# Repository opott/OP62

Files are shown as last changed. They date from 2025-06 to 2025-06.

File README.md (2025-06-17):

# OP62
This is a 60% (62 key) mechanical keyboard designed for Hackpad V2.

## PCB
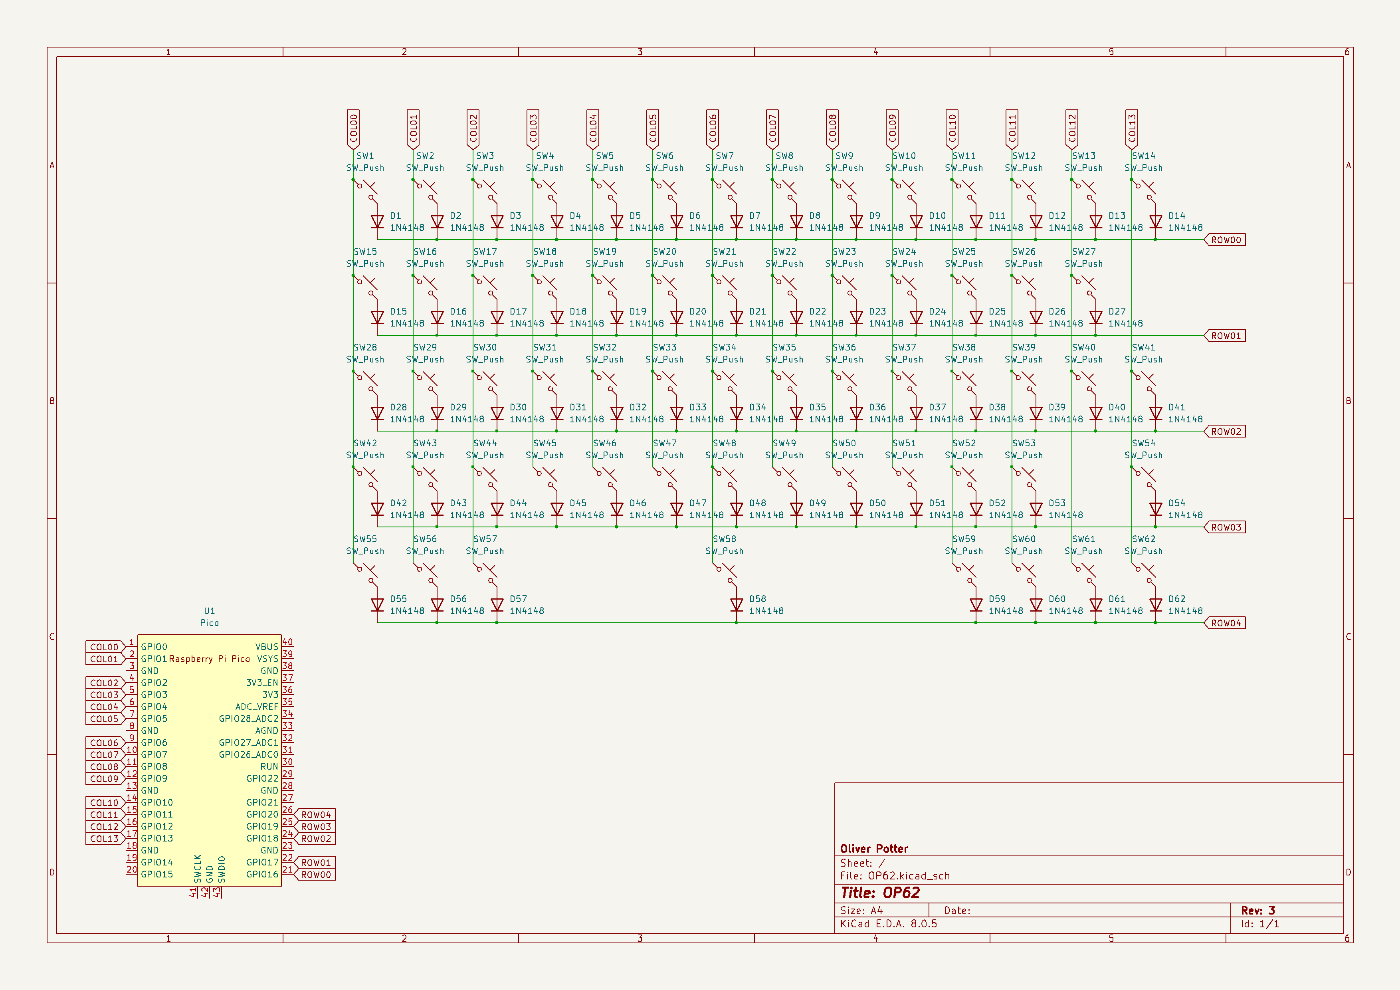
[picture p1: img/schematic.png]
schematic

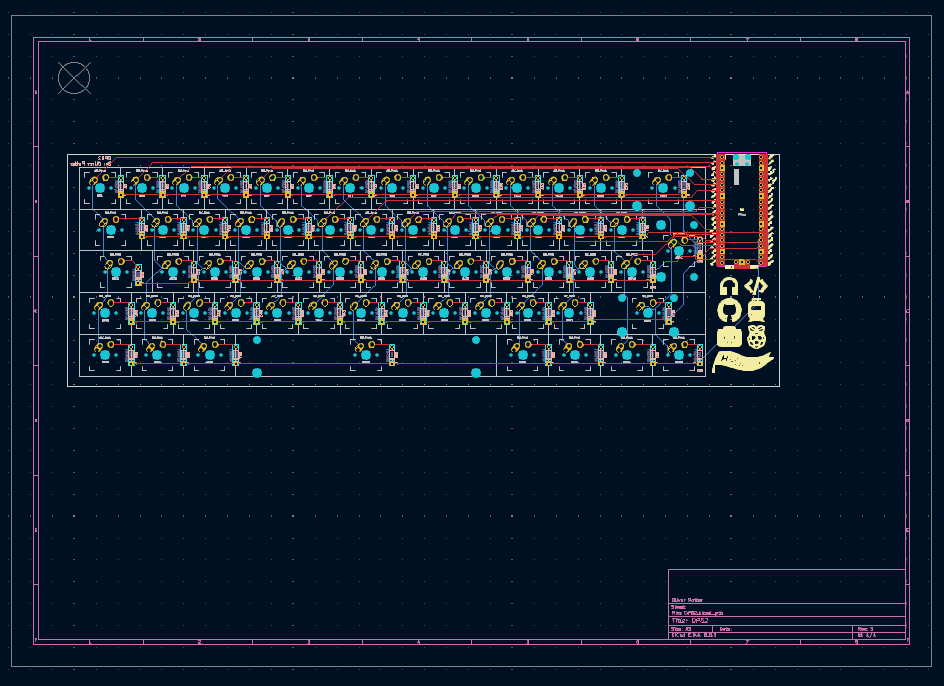
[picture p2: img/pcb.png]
pcb layout

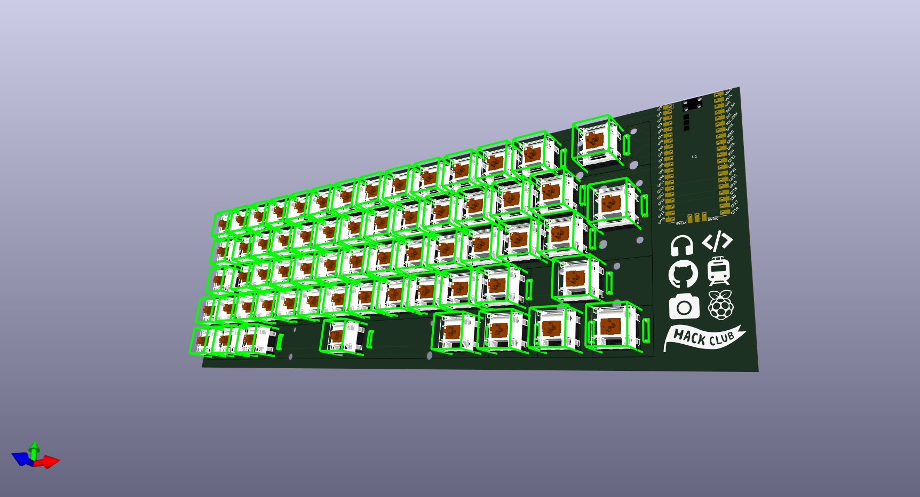
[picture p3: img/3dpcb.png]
3d view of pcb


## Case
The 3D printed case will consist of three parts:
- Top Assembly
- Plate
- Bottom Assembly

The top and bottom assembly will be attached with magnets. This is a screwless keyboard!
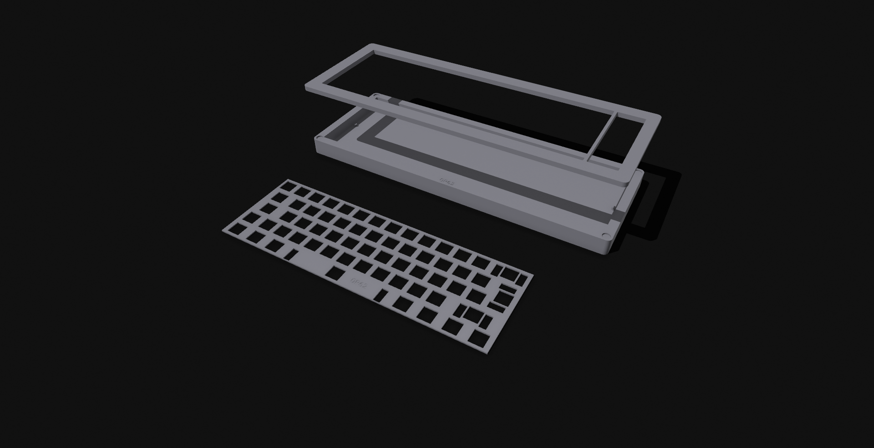
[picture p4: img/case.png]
case


## Firmware
The current firmware is a **VERY** basic prototype created with [Pog](https://pog.heaper.de/).

A final firmware version will be created upon recieving the hardware.

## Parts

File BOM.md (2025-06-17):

# OP62 - Bill of Materials
- PCB
    - **Vendor**: JLCPCB
    - **Price**: $28.77
        - **Merchandise Total:** $17.10
        - **Shipping Estimate:** $6.87
        - **Customs duties & taxes:** $4.80
- Orpheus Pico // Raspberry Pi Pico
    - With headers
    - To be supplied by HQ
- 3D Printed Case
    - To be printed by HQ
    - **Filament Colour:** White
- [Magnets](https://amzn.eu/d/0Vj31Tx)
    - **Purpose:** To hold the case together instead of screws.
    - **Vendor:** Amazon UK
    - **Price:** £5.99
- 62 [Prevail Epsilon Switches](https://www.mechmods.co.uk/products/prevail-epsilon-switches)
    - **Vendor:** MechMods UK
    - **Price:** 10 switches - £4.40 // Per switch ~£0.44 
- 62 1N4148 Diodes
- [White & Orange Double Shot PBT Keycaps](https://www.etsy.com/uk/listing/1345560507/isoansi-white-orange-double-shot-pbt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)
    - **Vendor:** KromeKeycaps // Etsy
    - **Price:** £24.99
- [TX AP Clip-in Stabilisers](https://www.mechmods.co.uk/products/tx-ap-clip-in-stabilisers?variant=44091474477279)
    - **Vendor:** MechMods UK
    - **Price:** £18.50

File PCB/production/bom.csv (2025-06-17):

Designator | Footprint | Quantity | Value | LCSC Part #
D1, D10, D11, D12, D13, D14, D15, D16, D17, D18, D19, D2, D20, D21, D22, D23, D24, D25, D26, D27, D28, D29, D3, D30, D31, D32, D33, D34, D35, D36, D37, D38, D39, D4, D40, D41, D42, D43, D44, D45, D46, D47, D48, D49, D5, D50, D51, D52, D53, D54, D55, D56, D57, D58, D59, D6, D60, D61, D62, D7, D8, D9 | D_DO-35_SOD27_P7.62mm_Horizontal | 62 | 1N4148
SW1, SW10, SW11, SW12, SW13, SW16, SW17, SW18, SW19, SW2, SW20, SW21, SW22, SW23, SW24, SW25, SW26, SW27, SW29, SW3, SW30, SW31, SW32, SW33, SW34, SW35, SW36, SW37, SW38, SW39, SW4, SW40, SW43, SW44, SW45, SW46, SW47, SW48, SW49, SW5, SW50, SW51, SW52, SW53, SW6, SW7, SW8, SW9 | MX-Alps-Hybrid-1U | 48 | SW_Push
SW14 | MX-Alps-Hybrid-2U | 1 | SW_Push
SW15 | MX-Alps-Hybrid-1.5U | 1 | SW_Push
SW28 | MX-Alps-Hybrid-1.75U | 1 | SW_Push
SW41 | MX-Alps-Hybrid-ISO | 1 | SW_Push
SW42, SW55, SW56, SW57, SW59, SW60, SW61, SW62 | MX-Alps-Hybrid-1.25U | 8 | SW_Push
SW54 | MX-Alps-Hybrid-2.75U | 1 | SW_Push
SW58 | MX-Alps-Hybrid-6.25U | 1 | SW_Push
U1 | RPi_Pico_SMD_TH | 1 | Pico

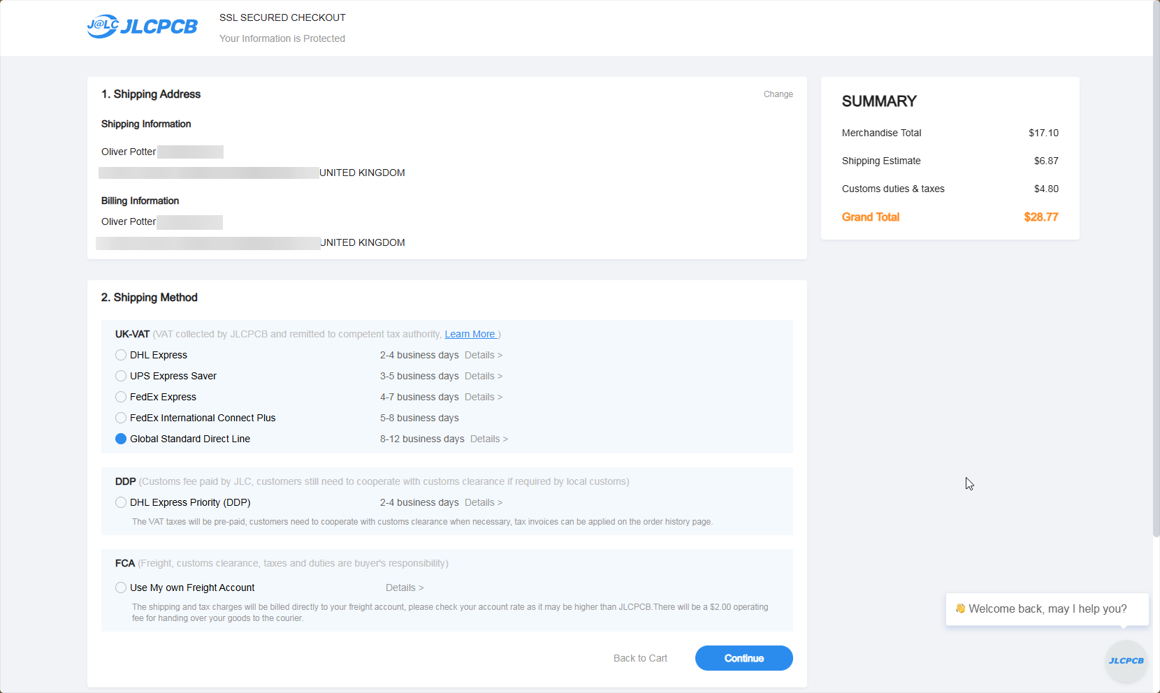
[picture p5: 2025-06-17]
img/bom/pcb.png

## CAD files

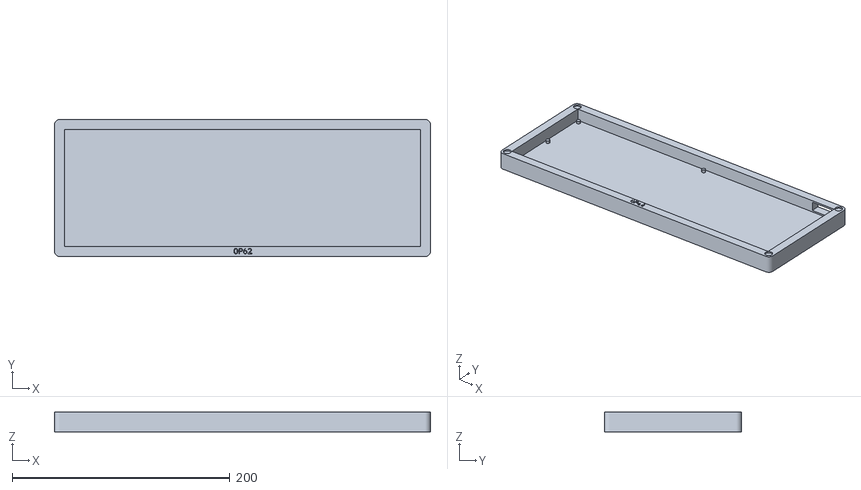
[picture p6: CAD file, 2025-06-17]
Production Files/Case/Bottom Assembly.stl
345.0 x 126.1 x 18.0

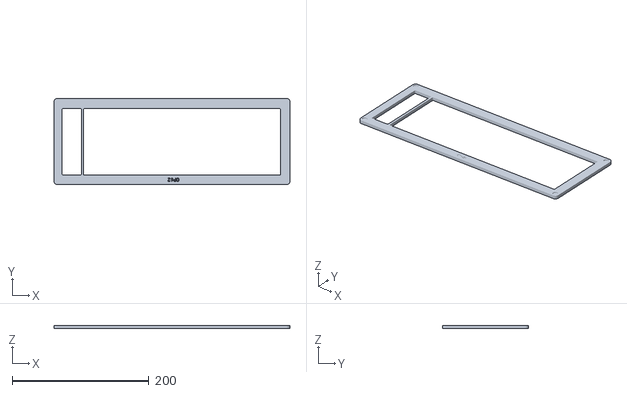
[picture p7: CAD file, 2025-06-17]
Production Files/Case/Top Assembly.stl
345.0 x 126.1 x 5.00

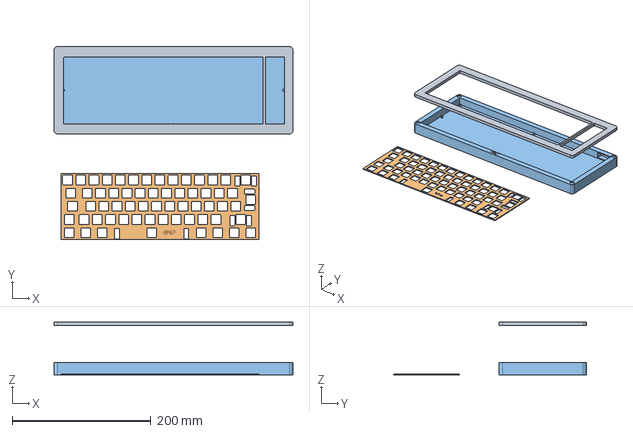
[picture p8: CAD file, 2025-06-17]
CAD/OP62.step
345.1 x 278.2 x 76.0 mm

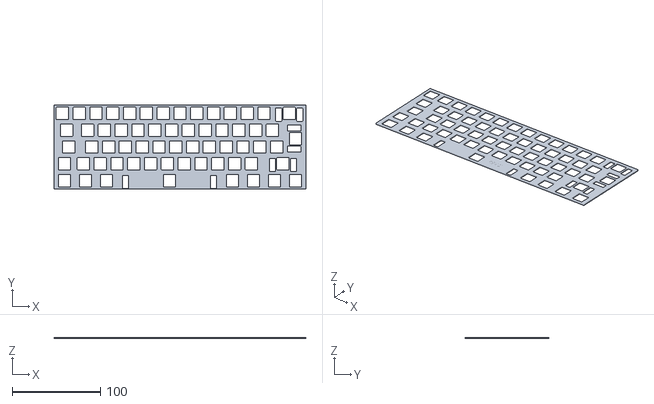
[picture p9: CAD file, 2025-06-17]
Production Files/Case/Plate.stl
285.8 x 95.2 x 1.50

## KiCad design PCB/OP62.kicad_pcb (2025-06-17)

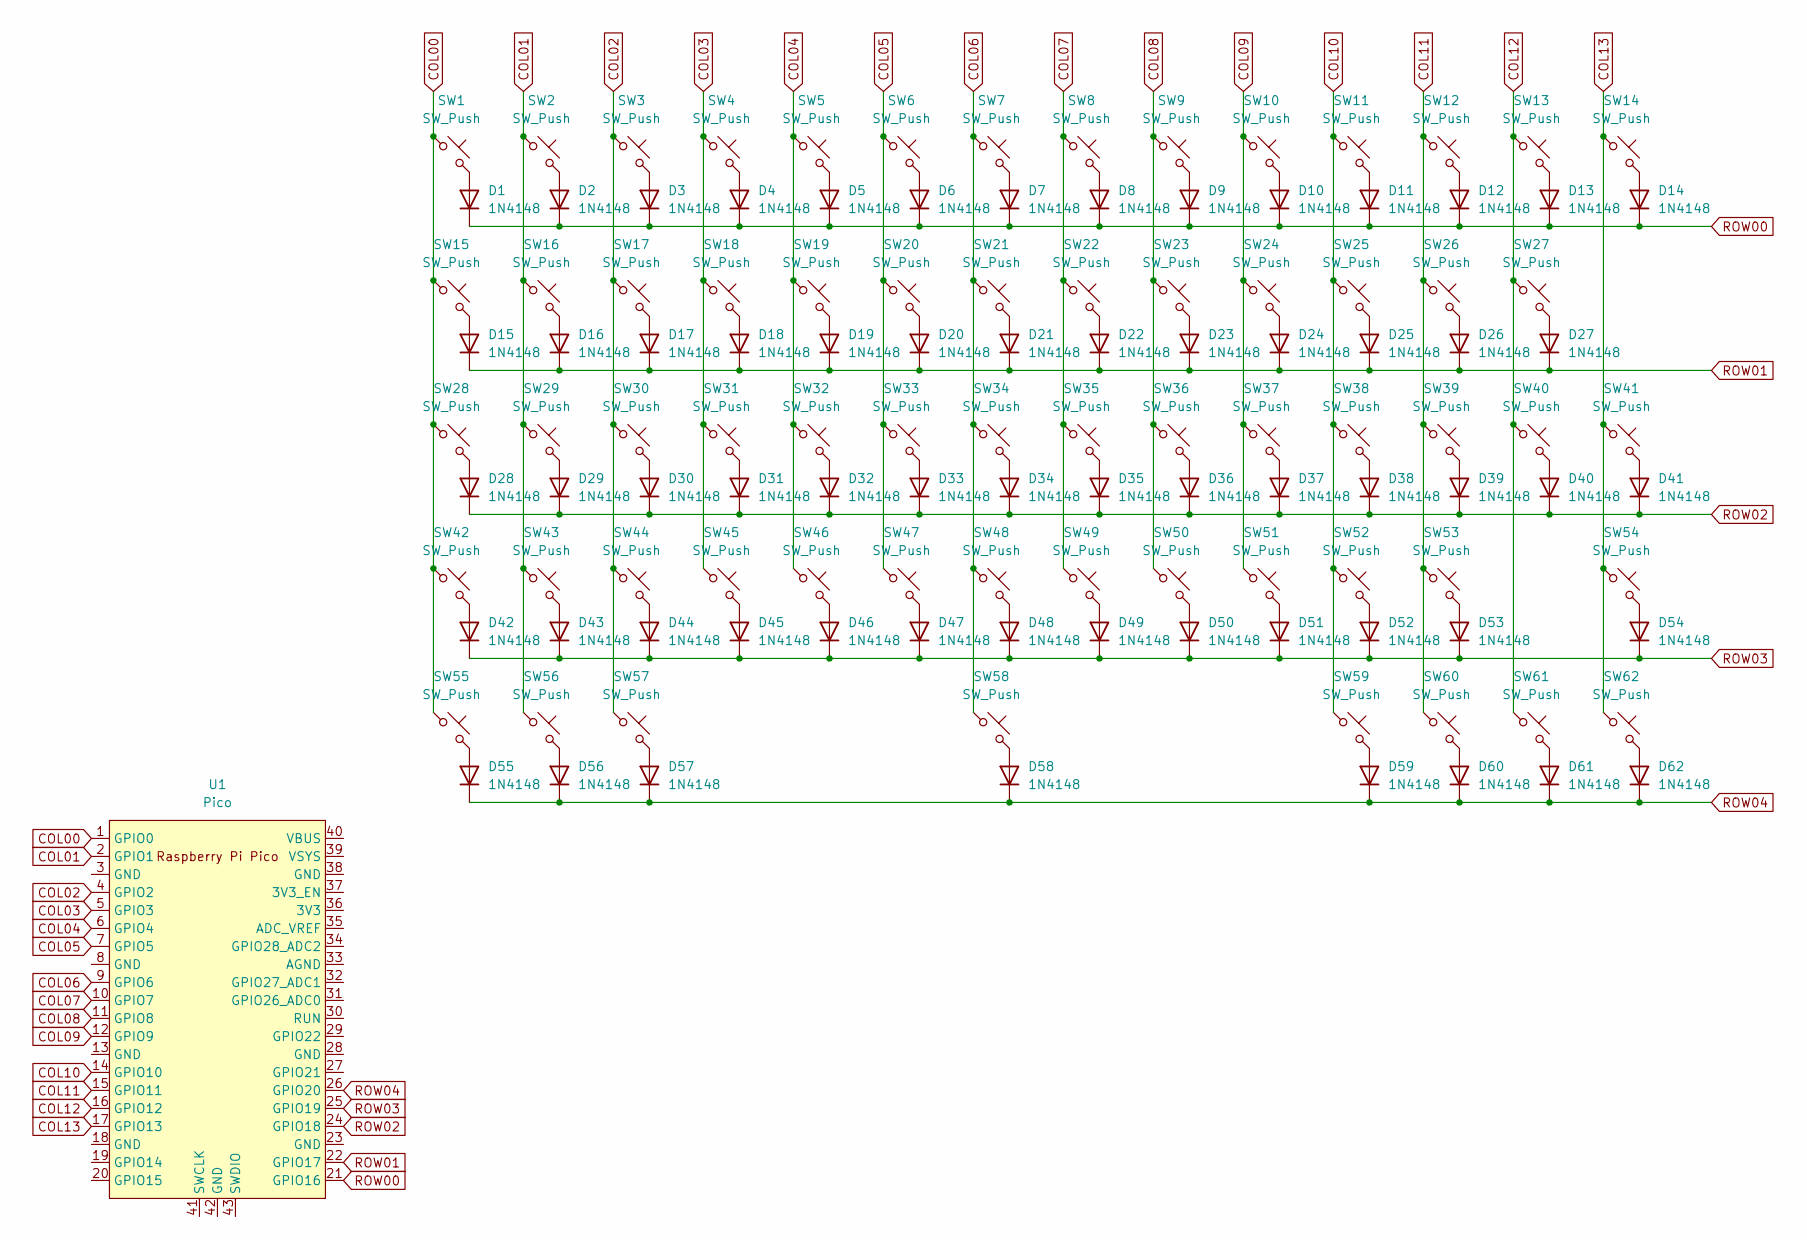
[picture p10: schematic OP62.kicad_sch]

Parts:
D1, D2, D3, D4, D5, D6, D7, D8, D9, D10, D11, D12, D13, D14, D15, D16, D17, D18, D19, D20, D21, D22, D23, D24, D25, D26, D27, D28, D29, D30, D31, D32, D33, D34, D35, D36, D37, D38, D39, D40, D41, D42, D43, D44, D45, D46, D47, D48, D49, D50, D51, D52, D53, D54, D55, D56, D57, D58, D59, D60, D61, D62: 1N4148; D_DO-35_SOD27_P7.62mm_Horizontal
SW1, SW2, SW3, SW4, SW5, SW6, SW7, SW8, SW9, SW10, SW11, SW12, SW13, SW16, SW17, SW18, SW19, SW20, SW21, SW22, SW23, SW24, SW25, SW26, SW27, SW29, SW30, SW31, SW32, SW33, SW34, SW35, SW36, SW37, SW38, SW39, SW40, SW43, SW44, SW45, SW46, SW47, SW48, SW49, SW50, SW51, SW52, SW53: SW_Push; MX-Alps-Hybrid-1U
SW14: SW_Push; MX-Alps-Hybrid-2U
SW15: SW_Push; MX-Alps-Hybrid-1.5U
SW28: SW_Push; MX-Alps-Hybrid-1.75U
SW41: SW_Push; MX-Alps-Hybrid-ISO
SW42, SW55, SW56, SW57, SW59, SW60, SW61, SW62: SW_Push; MX-Alps-Hybrid-1.25U
SW54: SW_Push; MX-Alps-Hybrid-2.75U
SW58: SW_Push; MX-Alps-Hybrid-6.25U
U1: Pico; RPi_Pico_SMD_TH

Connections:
COL00: SW1.1, SW15.1, SW28.1, SW42.1, SW55.1, U1.1 (GPIO0)
COL01: SW2.1, SW16.1, SW29.1, SW43.1, SW56.1, U1.2 (GPIO1)
COL02: SW3.1, SW17.1, SW30.1, SW44.1, SW57.1, U1.4 (GPIO2)
COL03: SW4.1, SW18.1, SW31.1, SW45.1, U1.5 (GPIO3)
COL04: SW5.1, SW19.1, SW32.1, SW46.1, U1.6 (GPIO4)
COL05: SW6.1, SW20.1, SW33.1, SW47.1, U1.7 (GPIO5)
COL06: SW7.1, SW21.1, SW34.1, SW48.1, SW58.1, U1.9 (GPIO6)
COL07: SW8.1, SW22.1, SW35.1, SW49.1, U1.10 (GPIO7)
COL08: SW9.1, SW23.1, SW36.1, SW50.1, U1.11 (GPIO8)
COL09: SW10.1, SW24.1, SW37.1, SW51.1, U1.12 (GPIO9)
COL10: SW11.1, SW25.1, SW38.1, SW52.1, SW59.1, U1.14 (GPIO10)
COL11: SW12.1, SW26.1, SW39.1, SW53.1, SW60.1, U1.15 (GPIO11)
COL12: SW13.1, SW27.1, SW40.1, SW61.1, U1.16 (GPIO12)
COL13: SW14.1, SW41.1, SW54.1, SW62.1, U1.17 (GPIO13)
unnamed: D1.2 (A), SW1.2
unnamed: D2.2 (A), SW2.2
unnamed: D3.2 (A), SW3.2
unnamed: D4.2 (A), SW4.2
unnamed: D5.2 (A), SW5.2
unnamed: D6.2 (A), SW6.2
unnamed: D7.2 (A), SW7.2
unnamed: D8.2 (A), SW8.2
unnamed: D9.2 (A), SW9.2
unnamed: D10.2 (A), SW10.2
unnamed: D11.2 (A), SW11.2
unnamed: D12.2 (A), SW12.2
unnamed: D13.2 (A), SW13.2
unnamed: D14.2 (A), SW14.2
unnamed: D15.2 (A), SW15.2
unnamed: D16.2 (A), SW16.2
unnamed: D17.2 (A), SW17.2
unnamed: D18.2 (A), SW18.2
unnamed: D19.2 (A), SW19.2
unnamed: D20.2 (A), SW20.2
unnamed: D21.2 (A), SW21.2
unnamed: D22.2 (A), SW22.2
unnamed: D23.2 (A), SW23.2
unnamed: D24.2 (A), SW24.2
unnamed: D25.2 (A), SW25.2
unnamed: D26.2 (A), SW26.2
unnamed: D27.2 (A), SW27.2
unnamed: D28.2 (A), SW28.2
unnamed: D29.2 (A), SW29.2
unnamed: D30.2 (A), SW30.2
unnamed: D31.2 (A), SW31.2
unnamed: D32.2 (A), SW32.2
unnamed: D33.2 (A), SW33.2
unnamed: D34.2 (A), SW34.2
unnamed: D35.2 (A), SW35.2
unnamed: D36.2 (A), SW36.2
unnamed: D37.2 (A), SW37.2
unnamed: D38.2 (A), SW38.2
unnamed: D39.2 (A), SW39.2
unnamed: D40.2 (A), SW40.2
unnamed: D41.2 (A), SW41.2
unnamed: D42.2 (A), SW42.2
unnamed: D43.2 (A), SW43.2
unnamed: D44.2 (A), SW44.2
unnamed: D45.2 (A), SW45.2
unnamed: D46.2 (A), SW46.2
unnamed: D47.2 (A), SW47.2
unnamed: D48.2 (A), SW48.2
unnamed: D49.2 (A), SW49.2
unnamed: D50.2 (A), SW50.2
unnamed: D51.2 (A), SW51.2
unnamed: D52.2 (A), SW52.2
unnamed: D53.2 (A), SW53.2
unnamed: D54.2 (A), SW54.2
unnamed: D55.2 (A), SW55.2
unnamed: D56.2 (A), SW56.2
unnamed: D57.2 (A), SW57.2
unnamed: D58.2 (A), SW58.2
unnamed: D59.2 (A), SW59.2
unnamed: D60.2 (A), SW60.2
unnamed: D61.2 (A), SW61.2
unnamed: D62.2 (A), SW62.2
ROW00: D1.1 (K), D2.1 (K), D3.1 (K), D4.1 (K), D5.1 (K), D6.1 (K), D7.1 (K), D8.1 (K), D9.1 (K), D10.1 (K), D11.1 (K), D12.1 (K), D13.1 (K), D14.1 (K), U1.21 (GPIO16)
ROW01: D15.1 (K), D16.1 (K), D17.1 (K), D18.1 (K), D19.1 (K), D20.1 (K), D21.1 (K), D22.1 (K), D23.1 (K), D24.1 (K), D25.1 (K), D26.1 (K), D27.1 (K), U1.22 (GPIO17)
ROW02: D28.1 (K), D29.1 (K), D30.1 (K), D31.1 (K), D32.1 (K), D33.1 (K), D34.1 (K), D35.1 (K), D36.1 (K), D37.1 (K), D38.1 (K), D39.1 (K), D40.1 (K), D41.1 (K), U1.24 (GPIO18)
ROW03: D42.1 (K), D43.1 (K), D44.1 (K), D45.1 (K), D46.1 (K), D47.1 (K), D48.1 (K), D49.1 (K), D50.1 (K), D51.1 (K), D52.1 (K), D53.1 (K), D54.1 (K), U1.25 (GPIO19)
ROW04: D55.1 (K), D56.1 (K), D57.1 (K), D58.1 (K), D59.1 (K), D60.1 (K), D61.1 (K), D62.1 (K), U1.26 (GPIO20)

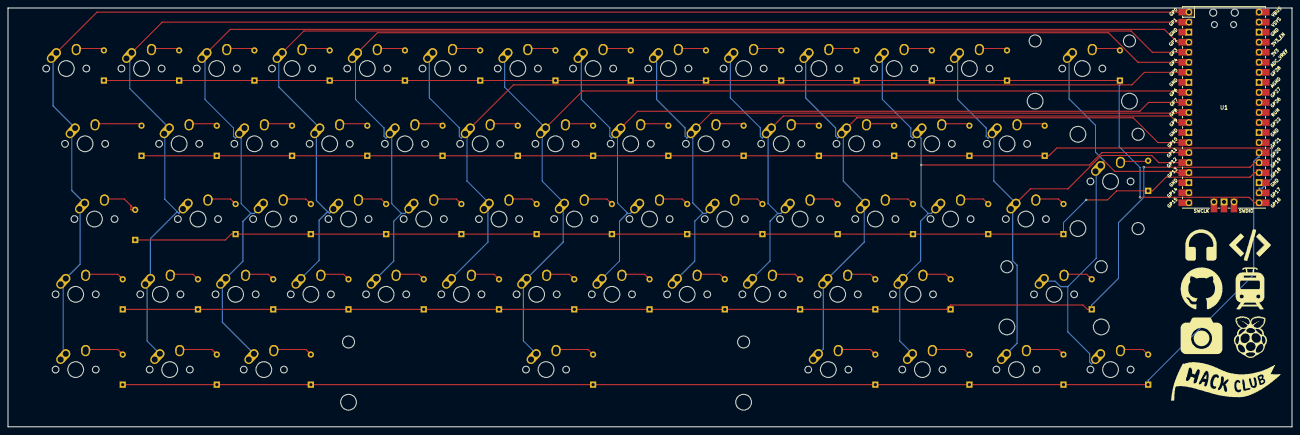
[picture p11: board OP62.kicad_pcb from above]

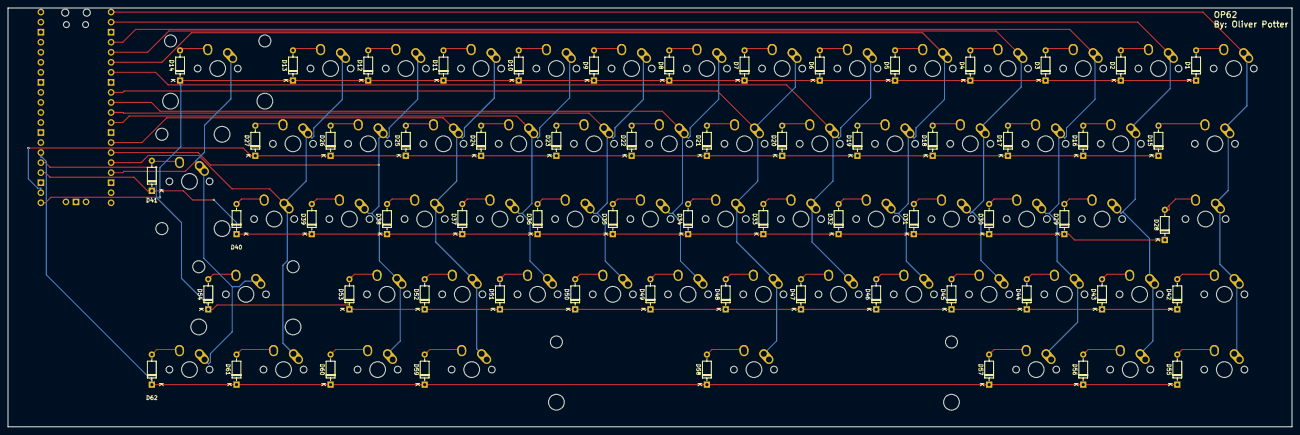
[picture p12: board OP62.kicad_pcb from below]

Board: 2 copper layers, 325.0 x 106.0 mm, 125 parts (62 on the bottom side), 81 nets.

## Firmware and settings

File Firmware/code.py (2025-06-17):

# Main Keyboard Configuration - v1.0.0
import board
import pog
# check if we just want to run the coord_mappping Assistant
if pog.coordMappingAssistant:
    from coordmaphelper import CoordMapKeyboard
    if __name__ == '__main__':
        CoordMapKeyboard().go()
    print("Exiting Coord Mapping Assistant Because of an error")
else:
    from kb import POGKeyboard
    # set the required features for you keyboard and keymap
    # add custom ones in the kb.py

    keyboard = POGKeyboard(features=pog.kbFeatures)

    # manage settings for our modules and extensions here
    keyboard.tapdance.tap_time = 200

    # Keymap
    import keymap
    keyboard.keymap = keymap.keymap

    # Encoder Keymap if available
    if pog.hasEncoders:
        keyboard.encoder_handler.map = keymap.encoderKeymap

    # Execute the keyboard loop
    if __name__ == '__main__':
        keyboard.go()
